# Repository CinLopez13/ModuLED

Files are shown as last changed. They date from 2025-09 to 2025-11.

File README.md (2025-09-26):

# ModuLED
Matriz led con doble función, Reloj Digital + Stacker Blocks

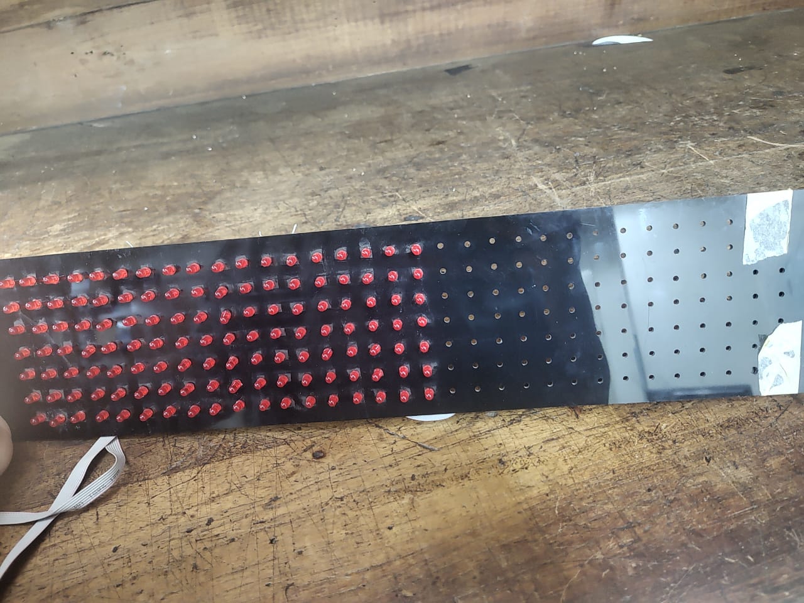
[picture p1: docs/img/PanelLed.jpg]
Prototipo


Es una Matriz de 18x7 que encontré en el LABI.

La idea es que tenga 2 funciones

Por un lado que sea un reloj digital para que quede en el LABI (a falta del reloj) 

Por otro lado quiero que tenga una función de "Game" para utilizar en los eventos del CDR (Como la feria del Libro o la Noche de los Museos). Este juego sería el stacker blocks

-> Dejo video de [Referencia](https://www.youtube.com/shorts/zlKPKK3Qink)

Para controlarlo decidí usar un modulo que controla matrices 8x8. Para cubrir todo el panel compré 3 modulos MAX7219 
Se va a programar con Arduino 

# Tareas 
- verificar que funcionan todos los Leds del panel 
- Soldar cables para conectar al modulo 
- Armar circuito con Arduino 
- Agregar mas Leds para hacer una matriz 24x7
- 

# Materiales
- Modulos MAX7219 x 3 
- Panel led del labi 
- Pines macho y hembra 
- Leds Rojo 3mm 
- Pistola de Silicona 

Objetivo: Una vez que funcione con Arduino la idea es programarlo con un ATMega del club (para esto hay que aprender a programar microcontroladores)

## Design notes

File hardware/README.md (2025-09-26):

El modulo MAX7219 viene con un display 8x8 para usar. 
El objetivo es poder hacer esa matriz 8x8 (En realidad 8x7) pero con el panel que ya tenemos 

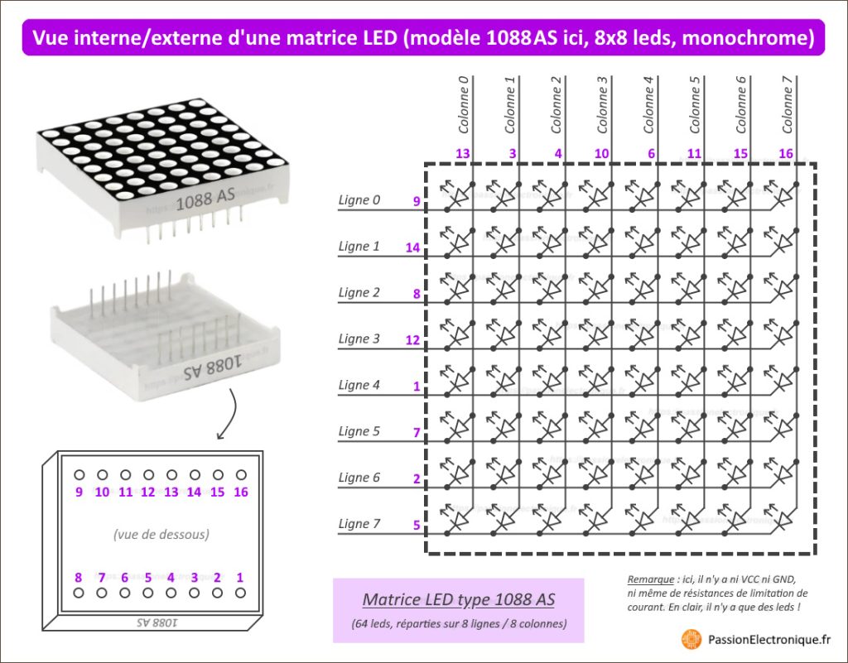
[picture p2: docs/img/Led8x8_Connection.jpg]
Display8x8


Se conectan al arduino VCC-GND-DIN-CS-CLK  Los pines donde esta DOUT son para conectar varios modulos 

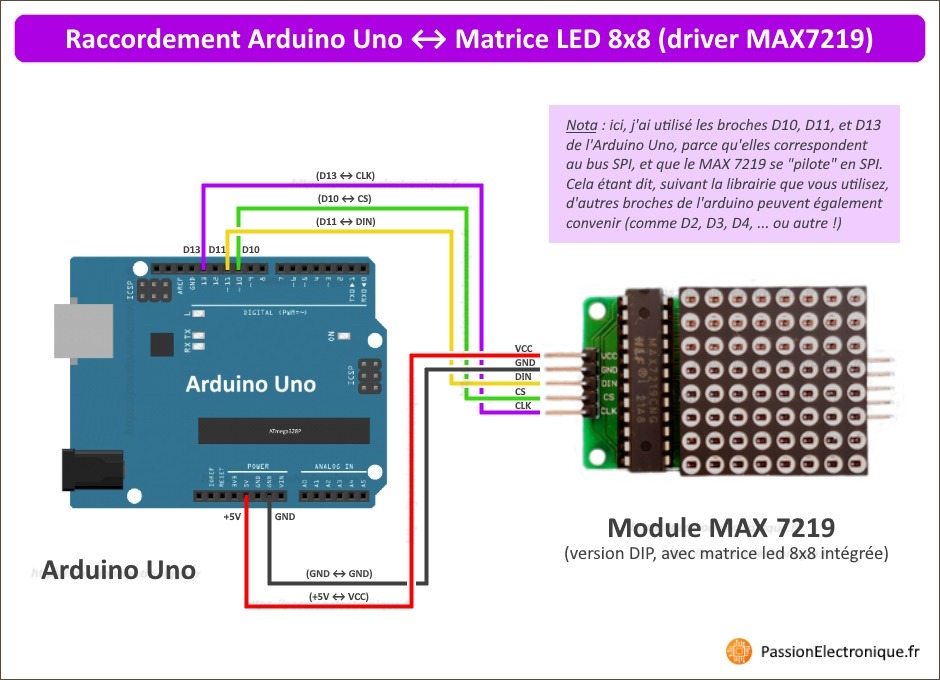
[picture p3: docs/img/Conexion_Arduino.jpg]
Arduino


Links de referencias para como utilizar el modulo MAX7219 

https://passionelectronique.fr/matrice-led-max7219-arduino/

https://www.pcbway.com/project/shareproject/LED_Dot_Matrix_MAX7219_1a67794a.html

https://www.14core.com/how-to-wire-8x8-matrix-led-with-max7219-on-arduino/

https://components101.com/displays/max7219-8x8-led-matrix-module

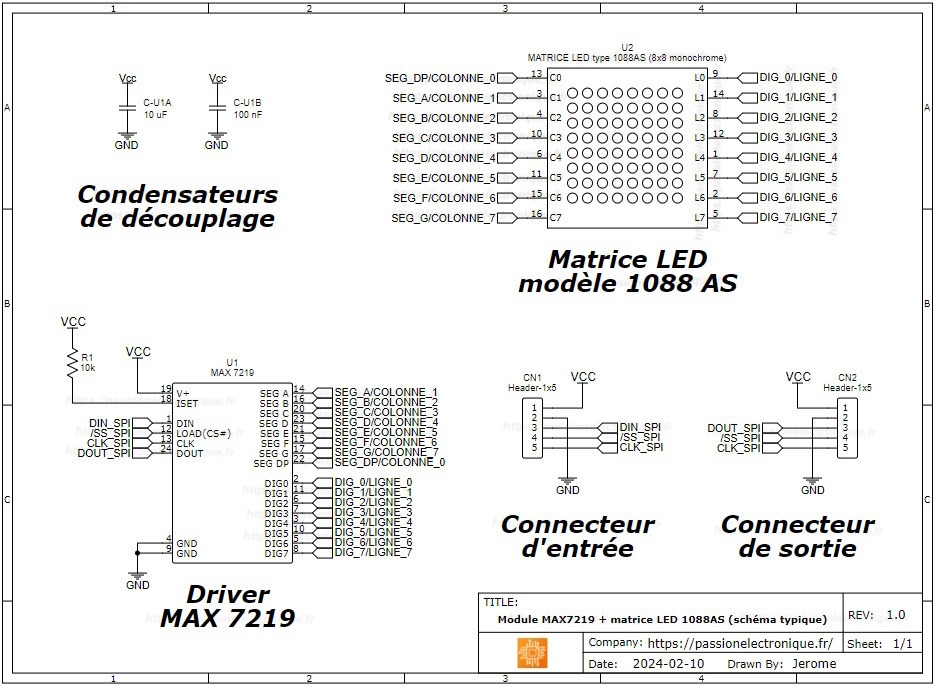
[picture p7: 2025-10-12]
docs/img/max7219-schematic-module-arduino-1088as-led-matrix.jpg

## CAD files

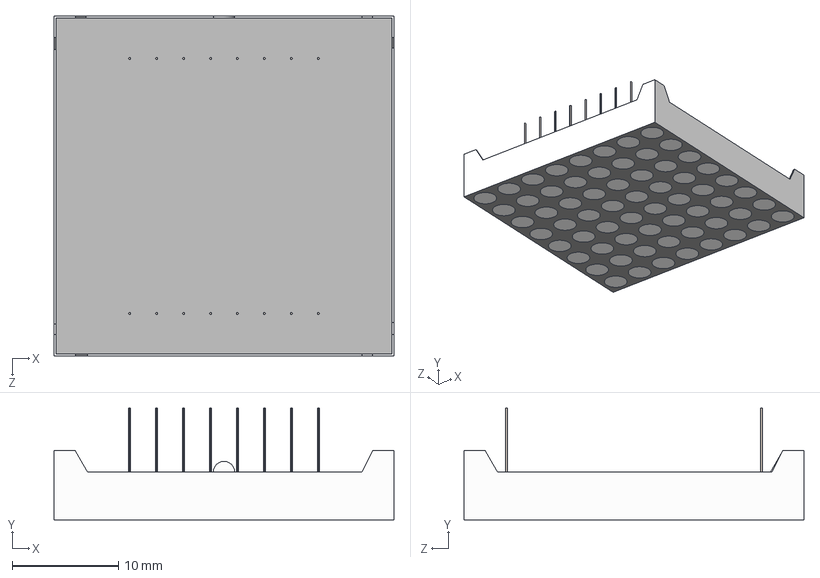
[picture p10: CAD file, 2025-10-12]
hardware/Display NH1088/kicad-LED_DotMatrix-main/kicad-LED_DotMatrix-main/3d_models/LED_1088.step
32.0 x 10.5 x 32.0 mm
1088-led_array
1088-shell
1088-lead x 16
1088-bottom-fill^1088

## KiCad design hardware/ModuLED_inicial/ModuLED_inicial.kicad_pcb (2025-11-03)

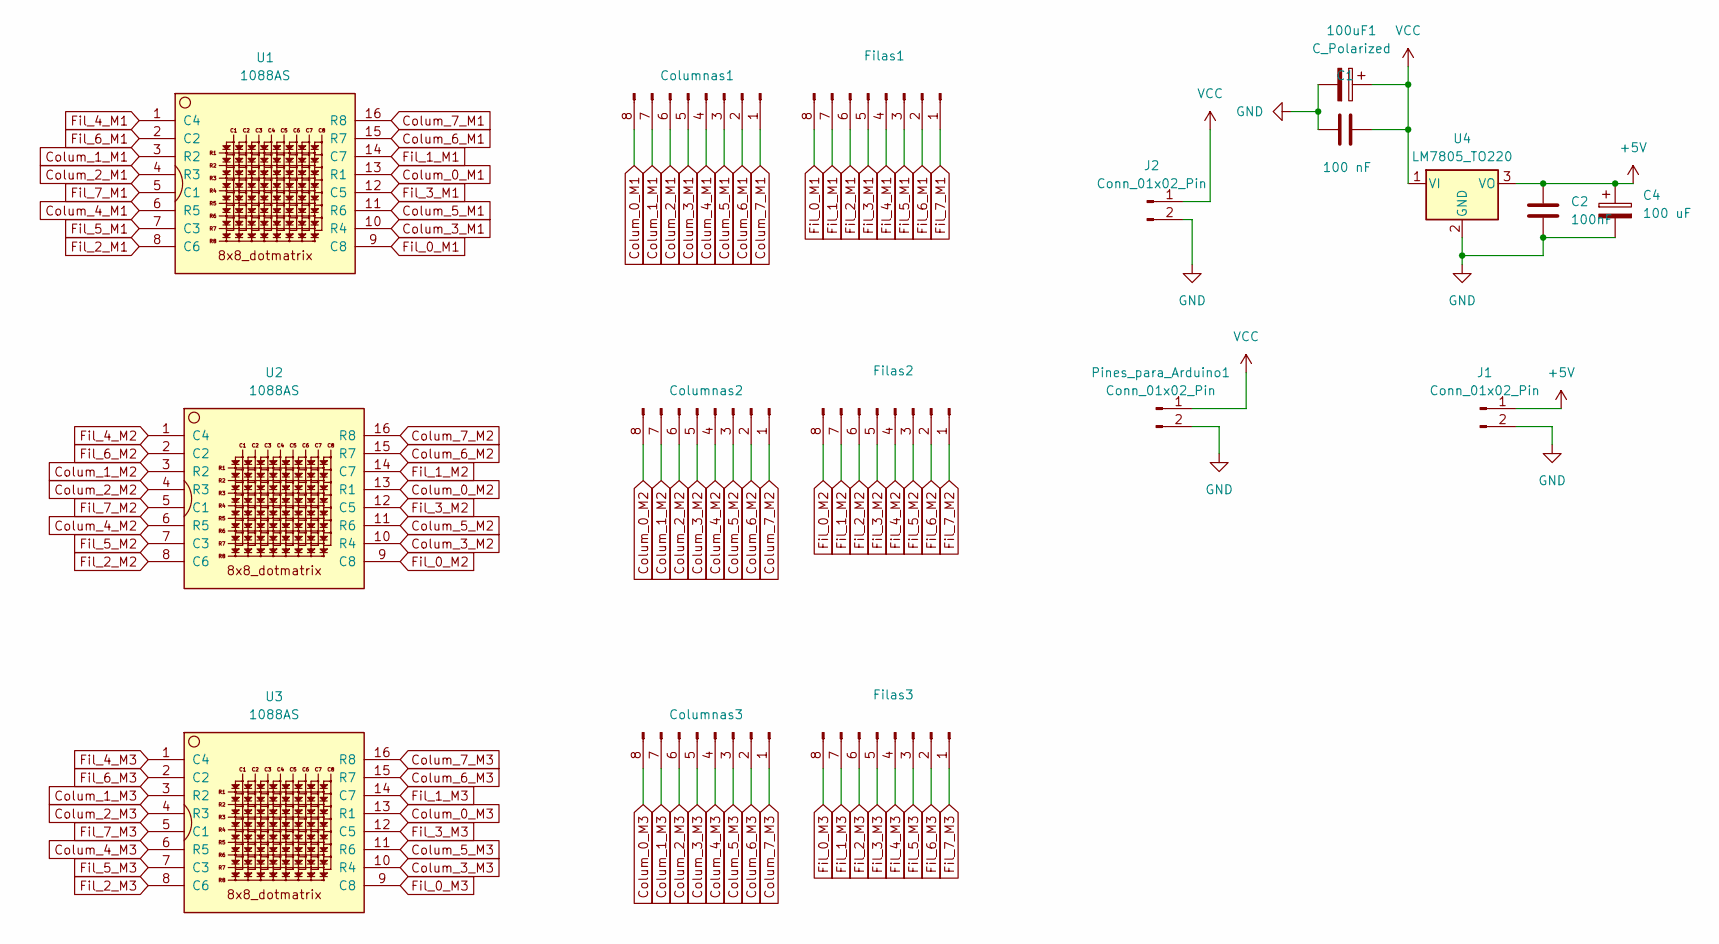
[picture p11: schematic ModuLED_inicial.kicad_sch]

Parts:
100uF1: C_Polarized; CP_Radial_D8.0mm_P2.50mm
C1: 100 nF; C_Disc_D3.4mm_W2.1mm_P2.50mm
C2: 100nF; C_Disc_D3.4mm_W2.1mm_P2.50mm
C4: 100 uF; CP_Radial_D8.0mm_P2.50mm
Columnas1, Columnas2, Columnas3: Conn_01x08_Pin; PinSocket_1x08_P2.54mm_Vertical
Filas1, Filas2, Filas3: Conn_01x08_Pin; PinSocket_1x08_P2.54mm_Vertical
J1: Conn_01x02_Pin; PinHeader_1x02_P2.54mm_Vertical
J2: Conn_01x02_Pin; Molex_KK-396_A-41791-0002_1x02_P3.96mm_Vertical
Pines_para_Arduino1: Conn_01x02_Pin; PinHeader_1x02_P2.54mm_Vertical
U1, U2, U3: 1088AS; LED_1088_Pin_Header
U4: LM7805_TO220; TO-220-3_Vertical

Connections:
+5V: C2.1, C4.1, J1.1, U4.3 (VO)
Colum_0_M1: Columnas1.8, U1.13 (R1)
Colum_0_M2: Columnas2.8, U2.13 (R1)
Colum_0_M3: Columnas3.8, U3.13 (R1)
Colum_1_M1: Columnas1.7, U1.3 (R2)
Colum_1_M2: Columnas2.7, U2.3 (R2)
Colum_1_M3: Columnas3.7, U3.3 (R2)
Colum_2_M1: Columnas1.6, U1.4 (R3)
Colum_2_M2: Columnas2.6, U2.4 (R3)
Colum_2_M3: Columnas3.6, U3.4 (R3)
Colum_3_M1: Columnas1.5, U1.10 (R4)
Colum_3_M2: Columnas2.5, U2.10 (R4)
Colum_3_M3: Columnas3.5, U3.10 (R4)
Colum_4_M1: Columnas1.4, U1.6 (R5)
Colum_4_M2: Columnas2.4, U2.6 (R5)
Colum_4_M3: Columnas3.4, U3.6 (R5)
Colum_5_M1: Columnas1.3, U1.11 (R6)
Colum_5_M2: Columnas2.3, U2.11 (R6)
Colum_5_M3: Columnas3.3, U3.11 (R6)
Colum_6_M1: Columnas1.2, U1.15 (R7)
Colum_6_M2: Columnas2.2, U2.15 (R7)
Colum_6_M3: Columnas3.2, U3.15 (R7)
Colum_7_M1: Columnas1.1, U1.16 (R8)
Colum_7_M2: Columnas2.1, U2.16 (R8)
Colum_7_M3: Columnas3.1, U3.16 (R8)
Fil_0_M1: Filas1.8, U1.9 (C8)
Fil_0_M2: Filas2.8, U2.9 (C8)
Fil_0_M3: Filas3.8, U3.9 (C8)
Fil_1_M1: Filas1.7, U1.14 (C7)
Fil_1_M2: Filas2.7, U2.14 (C7)
Fil_1_M3: Filas3.7, U3.14 (C7)
Fil_2_M1: Filas1.6, U1.8 (C6)
Fil_2_M2: Filas2.6, U2.8 (C6)
Fil_2_M3: Filas3.6, U3.8 (C6)
Fil_3_M1: Filas1.5, U1.12 (C5)
Fil_3_M2: Filas2.5, U2.12 (C5)
Fil_3_M3: Filas3.5, U3.12 (C5)
Fil_4_M1: Filas1.4, U1.1 (C4)
Fil_4_M2: Filas2.4, U2.1 (C4)
Fil_4_M3: Filas3.4, U3.1 (C4)
Fil_5_M1: Filas1.3, U1.7 (C3)
Fil_5_M2: Filas2.3, U2.7 (C3)
Fil_5_M3: Filas3.3, U3.7 (C3)
Fil_6_M1: Filas1.2, U1.2 (C2)
Fil_6_M2: Filas2.2, U2.2 (C2)
Fil_6_M3: Filas3.2, U3.2 (C2)
Fil_7_M1: Filas1.1, U1.5 (C1)
Fil_7_M2: Filas2.1, U2.5 (C1)
Fil_7_M3: Filas3.1, U3.5 (C1)
GND: 100uF1.2, C1.1, C2.2, C4.2, J1.2, J2.2, Pines_para_Arduino1.2, U4.2 (GND)
VCC: 100uF1.1, C1.2, J2.1, Pines_para_Arduino1.1, U4.1 (VI)

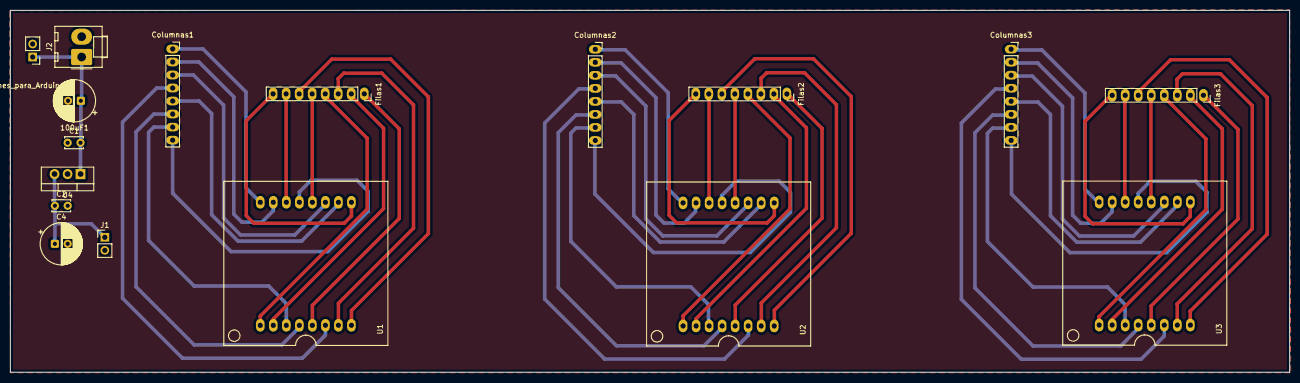
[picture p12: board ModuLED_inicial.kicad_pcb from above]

Board: 2 copper layers, 249.5 x 70.6 mm, 17 parts (0 on the bottom side), 51 nets.

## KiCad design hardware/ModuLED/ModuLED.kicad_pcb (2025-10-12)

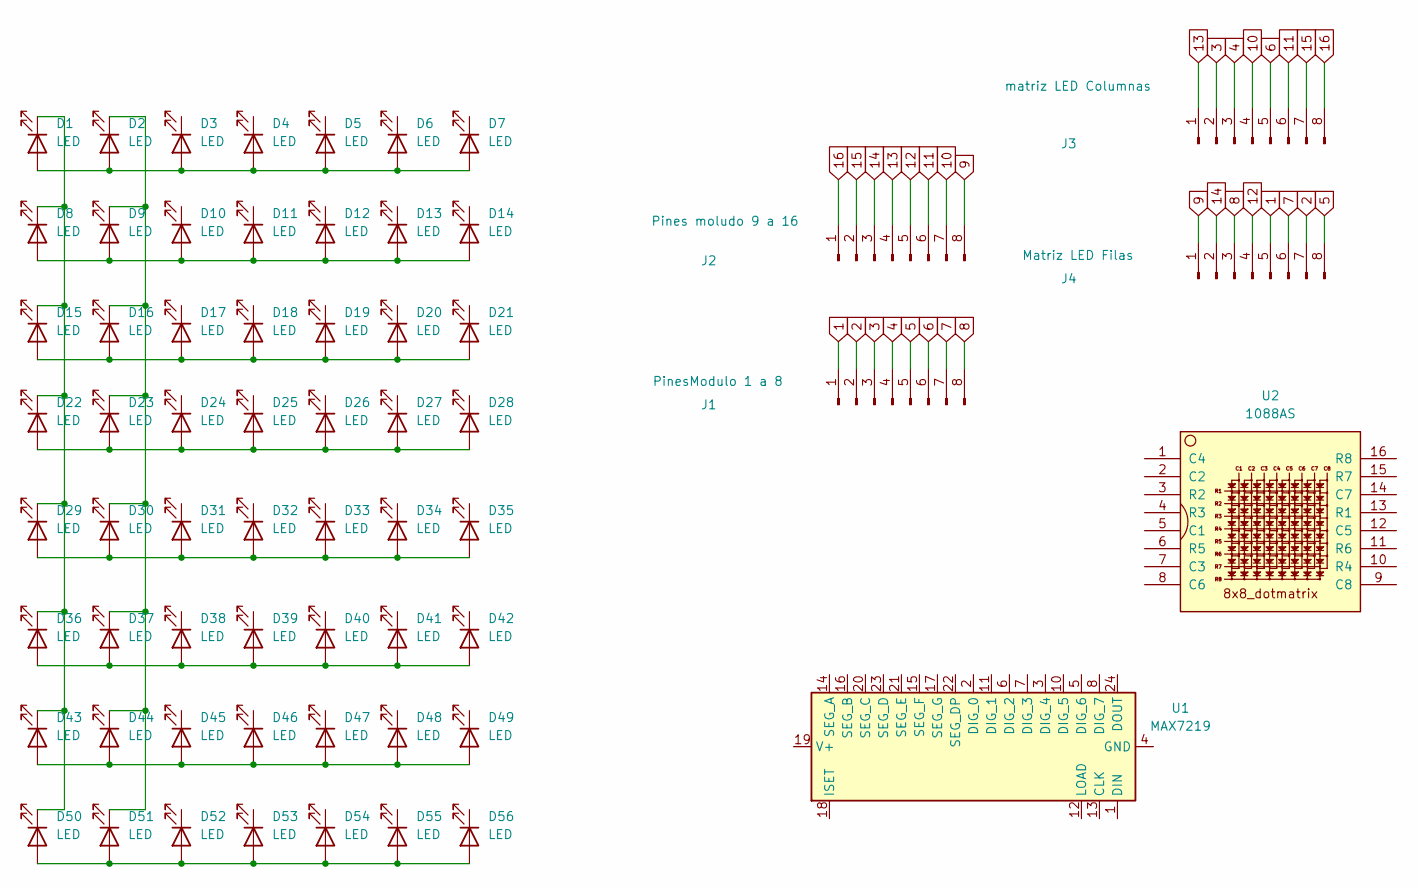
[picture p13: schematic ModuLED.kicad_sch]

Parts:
D1, D2, D3, D4, D5, D6, D7, D8, D9, D10, D11, D12, D13, D14, D15, D16, D17, D18, D19, D20, D21, D22, D23, D24, D25, D26, D27, D28, D29, D30, D31, D32, D33, D34, D35, D36, D37, D38, D39, D40, D41, D42, D43, D44, D45, D46, D47, D48, D49, D50, D51, D52, D53, D54, D55, D56: LED; LED_D3.0mm_Clear
J1: PinesModulo 1 a 8; Hirose_DF13-08P-1.25DSA_1x08_P1.25mm_Vertical
J2: Pines moludo 9 a 16; Hirose_DF13-08P-1.25DSA_1x08_P1.25mm_Vertical
J3: matriz LED Columnas; Hirose_DF13-08P-1.25DSA_1x08_P1.25mm_Vertical
J4: Matriz LED Filas; Hirose_DF13-08P-1.25DSA_1x08_P1.25mm_Vertical
U1: MAX7219; DIP-24_W7.62mm
U2: 1088AS; LED_1088_Pin_Header

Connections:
1: J1.1, J4.5
2: J1.2, J4.7
3: J1.3, J3.2
4: J1.4, J3.3
5: J1.5, J4.8
6: J1.6, J3.5
7: J1.7, J4.6
8: J1.8, J4.3
9: J2.8, J4.1
10: J2.7, J3.4
11: J2.6, J3.6
12: J2.5, J4.4
13: J2.4, J3.1
14: J2.3, J4.2
15: J2.2, J3.7
16: J2.1, J3.8
unnamed: D1.2 (A), D2.2 (A), D3.2 (A), D4.2 (A), D5.2 (A), D6.2 (A), D7.2 (A)
unnamed: D1.1 (K), D8.1 (K), D15.1 (K), D22.1 (K), D29.1 (K), D36.1 (K), D43.1 (K), D50.1 (K)
unnamed: D8.2 (A), D9.2 (A), D10.2 (A), D11.2 (A), D12.2 (A), D13.2 (A), D14.2 (A)
unnamed: D15.2 (A), D16.2 (A), D17.2 (A), D18.2 (A), D19.2 (A), D20.2 (A), D21.2 (A)
unnamed: D2.1 (K), D9.1 (K), D16.1 (K), D23.1 (K), D30.1 (K), D37.1 (K), D44.1 (K), D51.1 (K)
unnamed: D22.2 (A), D23.2 (A), D24.2 (A), D25.2 (A), D26.2 (A), D27.2 (A), D28.2 (A)
unnamed: D29.2 (A), D30.2 (A), D31.2 (A), D32.2 (A), D33.2 (A), D34.2 (A), D35.2 (A)
unnamed: D36.2 (A), D37.2 (A), D38.2 (A), D39.2 (A), D40.2 (A), D41.2 (A), D42.2 (A)
unnamed: D43.2 (A), D44.2 (A), D45.2 (A), D46.2 (A), D47.2 (A), D48.2 (A), D49.2 (A)
unnamed: D50.2 (A), D51.2 (A), D52.2 (A), D53.2 (A), D54.2 (A), D55.2 (A), D56.2 (A)
unnamed: U1.4 (GND), U1.9 (GND)

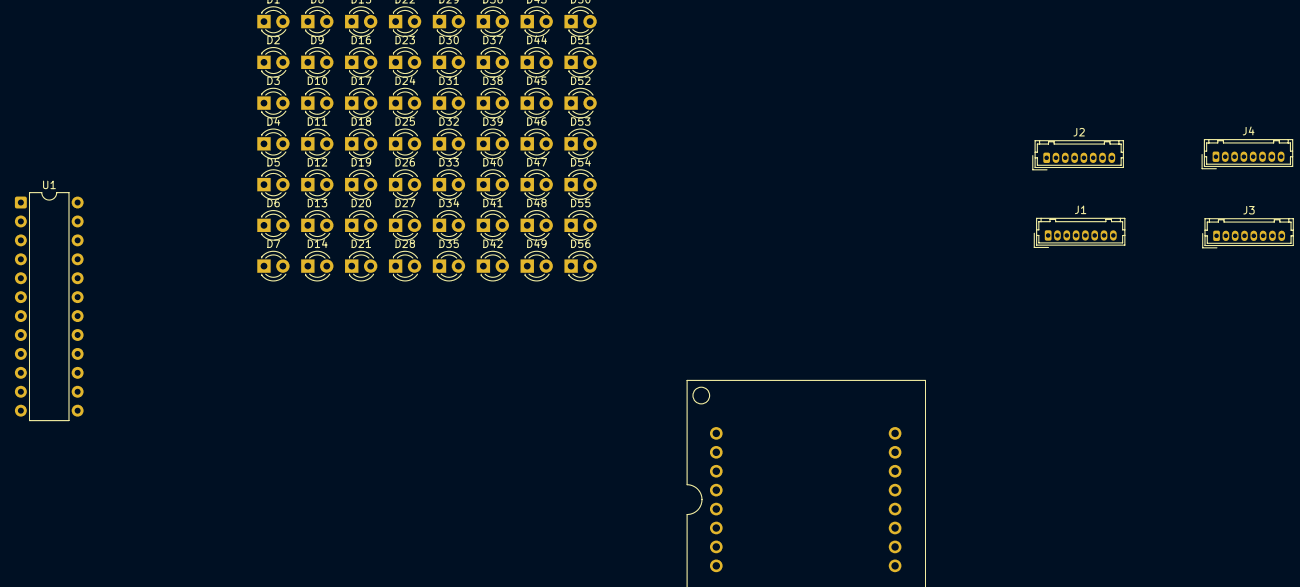
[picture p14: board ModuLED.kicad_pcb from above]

Board: 2 copper layers, 62 parts (0 on the bottom side), 27 nets.

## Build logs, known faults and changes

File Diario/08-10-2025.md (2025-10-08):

Hoy realice pruebas con el display y unos leds aparte que tenía 

Probe con una protoboad,un arduino uno y unos leds de 5mm ver como se manejan los pines jugando todo lo que es fila 1. Para el 0 0 conectando el anodo en el pin 13 y el cátodo en el pin 9, funcionó bien 

Cablear esto de manera directa va a ser muy complicado porquelo que decidi agregar una placa externa 

En esa placa van a ir varios pines soldados. Unos hembra para conectar el modulo MAX7219, para esto hay que soldarle pines macho mirando para abajo. Respetando el orden de los pins como en el display 

16 15 14 13 12 11 10 9
                            --->   Así estan en el modulo hecho para ese display 

1  2  3  4  5  6  7  8

Como se podía ver en la foto de como estaba internamente conectado el display voy a realizar esa conexión para otra tira de pines (Hembra o macho) para tener bien dispersado lo que es filas y columnas  

                                        13  3  4  10  6  11  15  16   --> Filas
                                                                                  --> Así me tienen que quedar los pines 
                                        9  14  8  12  1  7  2  5   --> Columnas

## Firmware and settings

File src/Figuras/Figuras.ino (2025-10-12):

#include <MD_MAX72xx.h> 
#include <SPI.h> 

// Defina el tipo de hardware, el tamaño y los pines 
#define HARDWARE_TYPE MD_MAX72XX::FC16_HW 
#define MAX_DEVICES 1 
#define PIN_CLK  7   // Pin D13 del Arduino (SCK) → pin CLK del módulo
#define PIN_CS   6   // Pin D10 del Arduino (CS o LOAD) → pin CS del módulo
#define PIN_DIN  5   // Pin D11 del Arduino (MOSI) → pin DIN del módulo

// Cree un objeto MAX72xx 
MD_MAX72XX display(HARDWARE_TYPE, PIN_DIN, PIN_CLK, PIN_CS, MAX_DEVICES);

// Mapas de bits para animaciones 
byte smiley[2][8] = { 
  {0b00111100, 0b01000010, 0b10100101, 0b10000001, 0b10100101, 0b10011001, 0b01000010, 0b00111100}, 
  {0b00111100, 0b01000010, 0b10100101, 0b10000001, 0b10111101, 0b10000001, 0b01000010, 0b00111100} 
}; 
byte heart[2][8] = { 
  {0b00000000, 0b01100110, 0b11111111, 0b11111111, 0b01111110, 0b00111100, 0b00011000, 0b00000000}, 
  {0b00000000, 0b01100110, 0b10111101, 0b10011001, 0b01000010, 0b00100100, 0b00011000, 0b00000000} } 
; 
byte xmark[2][8] = { 
  {0b10000001, 0b01000010, 0b00100100, 0b00011000, 0b00011000, 0b00100100, 0b01000010, 0b10000001}, 
  {0b00000000, 0b00000000, 0b00000000, 0b00000000, 0b00000000, 0b00000000, 0b00000000} } 
; 
byte spinningLine[4][8] = { 
  {0b00011000, 0b00111100, 0b01111110, 0b11111111, 0b11111111, 0b01111110, 0b00111100, 0b00011000}, 
  {0b00001000, 0b00011100, 0b00111110, 0b01111111, 0b01111111, 0b00111110, 0b00011100, 0b00001000}, 
  {0b00000000, 0b00011000, 0b00111100, 0b01111110, 0b01111110, 0b00111100, 0b00011000, 0b00000000}, 
  {0b00000000, 0b00000000, 0b00011000, 0b00111100, 0b00111100, 0b00011000, 0b00000000, 0b00000000} 
}; 
byte scrollingArrow[3][8] = { 
  {0b00100000, 0b00110000, 0b11101000, 0b11111100, 0b11101000, 0b00110000, 0b00100000, 0b00000000}, 
  {0b00010000, 0b00011000, 0b11110100, 0b11111110, 0b11110100, 0b00011000, 0b00010000, 0b00000000}, 
  {0b00001000, 0b00001100, 0b11111010, 0b11111111, 0b11111010, 0b00001100, 0b00001000, 0b00000000} 
}; 


// Definiciones de mapa de bits para caracteres ASCII 
const byte ASCII[][8] = { 
    {0x00, 0x00, 0x00, 0x00, 0x00, 0x00, 0x00, 0x00}, // Espacio (32) 
    {0x00, 0x00, 0x5F, 0x5F, 0x00, 0x00, 0x00, 0x00}, // ! (33) 
    {0x00, 0x07, 0x03, 0x00, 0x07, 0x03, 0x00, 0x00}, // " (34) 
    {0x14, 0x7F, 0x7F, 0x14, 0x7F, 0x7F, 0x14, 0x00}, // # (35) 
    {0x24, 0x2E, 0x6B, 0x6B, 0x3A, 0x12, 0x00, 0x00}, // $ (36) 
    {0x46, 0x66, 0x30, 0x18, 0x0C, 0x66, 0x62, 0x00}, // % (37) 
    {0x30, 0x7A, 0x4F, 0x5D, 0x37, 0x7A, 0x48, 0x00}, // & (38) 
    {0x00, 0x04, 0x07, 0x03, 0x00, 0x00, 0x00, 0x00}, // ' (39) 
    {0x00, 0x1C, 0x3E, 0x63, 0x41, 0x00, 0x00, 0x00}, // ( (40)
    {0x00, 0x41, 0x63, 0x3E, 0x1C, 0x00, 0x00, 0x00}, // ) (41)
    {0x08, 0x2A, 0x3E, 0x1C, 0x1C, 0x3E, 0x2A, 0x08}, // * (42)
    {0x08, 0x08, 0x3E, 0x3E, 0x08, 0x08, 0x00, 0x00}, // + (43)
    {0x00, 0x80, 0xE0, 0x60, 0x00, 0x00, 0x00, 0x00}, // , (44)
    {0x08, 0x08, 0x08, 0x08, 0x08, 0x08, 0x00, 0x00}, // - (45)
    {0x00, 0x00, 0x60, 0x60, 0x00, 0x00, 0x00, 0x00}, // . (46)
    {0x60, 0x30, 0x18, 0x0C, 0x06, 0x03, 0x01, 0x00}, // / (47)
    {0x3E, 0x7F, 0x59, 0x4D, 0x7F, 0x3E, 0x00, 0x00}, // 0 (48)
    {0x42, 0x42, 0x7F, 0x7F, 0x40, 0x40, 0x00, 0x00}, // 1 (49)
    {0x62, 0x73, 0x59, 0x49, 0x6F, 0x66, 0x00, 0x00}, // 2 (50)
    {0x22, 0x63, 0x49, 0x49, 0x7F, 0x36, 0x00, 0x00}, // 3 (51)
    {0x18, 0x1C, 0x52, 0x7F, 0x7F, 0x50, 0x00, 0x00}, // 4 (52)
    {0x2F, 0x6F, 0x45, 0x45, 0x7D, 0x39, 0x00, 0x00}, // 5 (53)
    {0x3E, 0x7F, 0x49, 0x49, 0x79, 0x30, 0x00, 0x00}, // 6 (54)
    {0x03, 0x03, 0x71, 0x79, 0x0F, 0x07, 0x00, 0x00}, // 7 (55)
    {0x36, 0x7F, 0x49, 0x49, 0x7F, 0x36, 0x00, 0x00}, // 8 (56)
    {0x06, 0x4F, 0x49, 0x49, 0x7F, 0x3E, 0x00, 0x00}, // 9 (57)
    {0x00, 0x00, 0x66, 0x66, 0x00, 0x00, 0x00, 0x00}, // : (58)
    {0x00, 0x80, 0xE6, 0x66, 0x00, 0x00, 0x00, 0x00}, // ; (59)
    {0x08, 0x1C, 0x36, 0x63, 0x41, 0x00, 0x00, 0x00}, // < (60)
    {0x24, 0x24, 0x24, 0x24, 0x24, 0x24, 0x00, 0x00}, // = (61)
    {0x00, 0x41, 0x63, 0x36, 0x1C, 0x08, 0x00, 0x00}, // > (62)
    {0x02, 0x03, 0x51, 0x59, 0x0F, 0x06, 0x00, 0x00}, // ? (63)
    {0x3E, 0x7F, 0x41, 0x5D, 0x55, 0x1F, 0x1E, 0x00}, // @ (64)
    {0x7C, 0x7E, 0x13, 0x13, 0x7E, 0x7C, 0x00, 0x00}, // A (65)
    {0x41, 0x7F, 0x7F, 0x49, 0x49, 0x7F, 0x36, 0x00}, // B (66)
    {0x1C, 0x3E, 0x63, 0x41, 0x41, 0x63, 0x22, 0x00}, // C (67)
    {0x41, 0x7F, 0x7F, 0x41, 0x63, 0x3E, 0x1C, 0x00}, // D (68)
    {0x41, 0x7F, 0x7F, 0x49, 0x5D, 0x41, 0x63, 0x00}, // E (69)
    {0x41, 0x7F, 0x7F, 0x49, 0x1D, 0x01, 0x03, 0x00}, // F (70)
    {0x1C, 0x3E, 0x63, 0x41, 0x51, 0x73, 0x72, 0x00}, // G (71)
    {0x7F, 0x7F, 0x08, 0x08, 0x7F, 0x7F, 0x00, 0x00}, // H (72)
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
};

// Scrolling text message
const char *scrollingText = " Components101 ";
uint16_t scrollDelay = 100; // Delay between shifts in milliseconds
uint16_t displayTime = 500; // Time each frame is shown in milliseconds
int brightnessLevel = 8; // Set brightness level (0 is minimum, 15 is maximum)

void setup() {
  Serial.begin(115200);
  display.begin(); // Initialize the display
  display.control(MD_MAX72XX::INTENSITY, brightnessLevel); // Set the brightness level
  display.clear(); // Clear the display
}

void loop() {
  playAnimation(smiley, 2, 2);
  playAnimation(heart, 2, 2);

  scrollText(scrollingText);
  playAnimation(xmark, 2, 2);
  playAnimation(spinningLine, 4, 2);
  playAnimation(scrollingArrow, 3, 2);
}

void playAnimation(byte animation[][8], int frameCount, int repeat) {
  for (int r = 0; r < repeat; r++) {
    for (int i = 0; i < frameCount; i++) {
      displayFrame(animation[i]);
      delay(displayTime); // Wait before showing next frame
    }
  }
}

void playRandomFlash(int count, int repeat) {
  for (int r = 0; r < repeat; r++) {
    for (int i = 0; i < count; i++) {
      byte row = rand() % 8;
      byte col = rand() % 8;
      display.setPoint(row, col, true);  // Turn on a random LED
      display.update();
      delay(50);  // Short flash
      display.setPoint(row, col, false); // Turn off the LED
      display.update();
    }
  }
}

void displayFrame(byte frame[8]) {
  for (int i = 0; i < 8; i++) {
    display.setRow(0, i, frame[i]); // Display each row of the bitmap
  }
  display.update(); // Ensure the display is updated
}
void scrollText(const char *pText) {
    int textLength = strlen(pText);
    int maxPosition = textLength * 8; // Total pixels to scroll

    
    for (int position = -MAX_DEVICES * 8; position < maxPosition; position++) { 
        display.clear(); // Asegúrese de que la pantalla se borre en cada fotograma 

        for (int col = 0; col < MAX_DEVICES * 8; col++) { 
            int charIndex = (position + col) / 8; 
            int colInChar = (position + col) % 8; 

            if (charIndex >= 0 && charIndex < textLength) { 
                char ch = pText[charIndex]; 
                int bitmapIndex = ch - 32; // Calcule el índice correcto en la matriz de mapa de bits 

                if (bitmapIndex >= 0 && bitmapIndex < sizeof(ASCII) / sizeof(ASCII[0])) { 
                    byte columnData = ASCII[bitmapIndex][colInChar]; 
                    display.setColumn(MAX_DEVICES * 8 - 1 - col, columnData); 
                } else { 
                    display.setColumn(MAX_DEVICES * 8 - 1 - col, 0x00); 
                } 
            } else { 
                display.setColumn(MAX_DEVICES * 8 - 1 - col, 0x00); 
            } 
        } 
        display.update(); 
        delay(scrollDelay); 
        if (position == -MAX_DEVICES * 8) { 
            Serial.print("Posición inicial: "); 
            Serial.println(position); 
            Serial.print("Primer carácter: "); 
            Serial.println(pText[0]); 
        } 
    } 
}

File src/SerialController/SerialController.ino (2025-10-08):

#include <LedControl.h>

#define PIN_CLK  7   // Pin D13 del Arduino (SCK) → pin CLK del módulo
#define PIN_CS   6   // Pin D10 del Arduino (CS o LOAD) → pin CS del módulo
#define PIN_DIN  5   // Pin D11 del Arduino (MOSI) → pin DIN del módulo

#define adress 0

LedControl matrixLed = LedControl(PIN_DIN, PIN_CLK, PIN_CS, 1);

uint8_t data[8][8] = {0};

void setup() {
  // put your setup code here, to run once:

  Serial.begin(115200);
  matrixLed.shutdown(adress, false);       // shutdown     : "true" active le mode "sommeil", tandis que "false" active le mode "normal"
  matrixLed.setIntensity(adress, 5);       // setIntensity : valeur pouvant aller de 0 à 15 (pour 16 niveaux de luminosité, donc)
  matrixLed.clearDisplay(adress);
}

void loop() {
  if (Serial.available()) {
    String input = Serial.readStringUntil('\n'); // Leer hasta nueva línea
    input.trim(); // Eliminar espacios iniciales y finales

    int spaceIndex = input.indexOf(' ');
    if (spaceIndex > 0) {
      String param1Str = input.substring(0, spaceIndex);
      String param2Str = input.substring(spaceIndex + 1);

      int param1 = param1Str.toInt();
      int param2 = param2Str.toInt();

      // Verificación básica
      if (param1Str.length() > 0 && param2Str.length() > 0) {
        data[param1][param2] = !data[param1][param2];
        matrixLed.setLed(adress, param1, param2, data[param1][param2]);
      } else {
        Serial.println("Error: entradas invalidas.");
      }
    } else {
      Serial.println("Error: se requieren dos numeros separados por un espacio.");
    }
  }
}

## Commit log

2025-09-25 Carpeta de fotos
2025-09-26 Esquemático
    [ModuLED.kicad_pcb, ModuLED.kicad_sch]
2025-09-26 pines arduino
2025-10-12 Diseño
    Se sumo el esquemático y huella del display 1088 y arme un nuevo proyecto en kiCAD para ver como conectar los pines en la primera version de la placa
    [LED_1088.step, ModuLED.kicad_pcb, ModuLED.kicad_sch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]
2025-11-03 Primera Placa
    Diseño de la primera placa para esta matriz, hecha para que tenga alimentación por batería con un regulador y los pines para sacar loscables que conecten a las entradas y salidas de los modulos. Desp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
    [ModuLED_inicial.kicad_pcb, ModuLED_inicial.kicad_sch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]
